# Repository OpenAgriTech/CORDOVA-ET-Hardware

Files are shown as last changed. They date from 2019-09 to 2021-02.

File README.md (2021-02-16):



# CORDOVA-ET-Hardware
Hardware parts for the CORDOVA-ET system.

## What is CORDOVA-ET?
The COnductance Recording Device for Observation and Validation of EvapoTranspiration (CORDOVA-ET) is a set of different components and instruments designed to record micrometeorological variables required for the calculation of evapotranspiration (ET) using the energy balance (EB) method. It has been developed by the University of Cordoba ([UCO](https://www.uco.es/)) and the [IAS-CSIC](https://www.ias.csic.es/) as part of the [SIDA-FAO project](http://www.fao.org/3/ca8794en/CA8794EN.pdf).

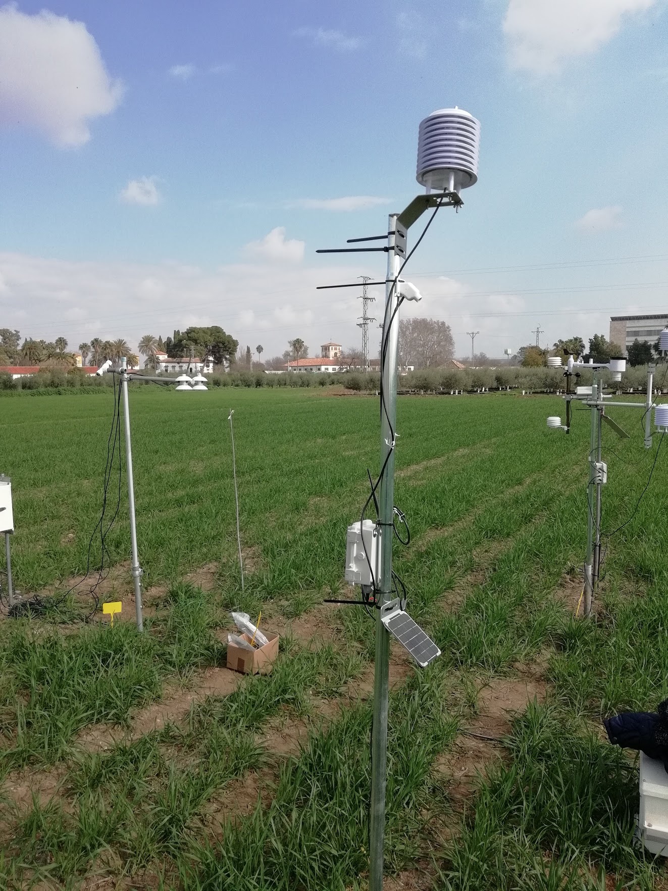
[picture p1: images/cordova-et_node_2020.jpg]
CORDOVA-ET Node during field validation in Cordoba 2020


For more information, you can join FAO's D-Groups on Water Productiviy and Agriculture, where you can view the webinars explaining the system and download manuals and troubleshooting guides. [D-groups access](https://dgroups.org/fao/waterproductivity/cordova_et)

## Hardware
The system consists on a group of LoRaWAN nodes that can measure simultaneously infrared temperature, air temperature and humidity as well as solar radiation.

This repository contains the design files to build a node yourself, including PCBs and 3D printed parts.

## Software
The code for the nodes can be found [here](https://github.com/OpenAgriTech/CORDOVA-ET-node)

## License
Licensed under Creative Commons Attribution-NonCommercial-ShareAlike 4.0 International (CC BY-NC-SA 4.0). See LICENSE.md for more info.

IAS-CSIC & University of Cordoba, 2021

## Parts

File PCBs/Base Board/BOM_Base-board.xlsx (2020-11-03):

Designator | Manufacturer Part Number or Seeed SKU | Qty | Link
J7 | 640453-6 | 1 | https://www.seeedstudio.io/opl.html
U5 | B2B-PH-K-S(LF)(SN) | 1 | https://www.seeedstudio.io/opl.html
J6 | 1751251 | 1 | https://www.seeedstudio.io/opl.html
R1,R4 | RC0603FR-074K7L | 2 | https://www.seeedstudio.io/opl.html
J8,J1 | 1125S-4P | 2 | https://www.seeedstudio.io/opl.html
J4 | 1125S-4P | 1 | https://www.seeedstudio.io/opl.html
J5 | 1125S-4P | 1 | https://www.seeedstudio.io/opl.html
J9 | 1125S-4P | 1 | https://www.seeedstudio.io/opl.html
R5 | RC0603FR-07115KL | 1 | https://www.seeedstudio.io/opl.html
R6 | RC0603FR-0756KL | 1 | https://www.seeedstudio.io/opl.html
SW1 | JS202011SCQN | 1 | https://www.seeedstudio.io/opl.html

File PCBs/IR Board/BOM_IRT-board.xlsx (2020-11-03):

Designator | MNP | Qty | Link
U1 | XC6206P302MR | 1 | https://statics3.seeedstudio.com/images/opl/datasheet/310030009.pdf
C3 | TAJA106K016RNJ | 1 | https://statics3.seeedstudio.com/images/opl/datasheet/0130050P1.pdf
C1,C2 | CC0402KRX7R8BB104 | 2 | https://statics3.seeedstudio.com/images/opl/datasheet/302010024.pdf
R1,R2 | RC0603FR-074K7L | 2 | https://statics3.seeedstudio.com/images/opl/datasheet/resistance-series.pdf
J2 | 1125S-4P | 1 | https://statics3.seeedstudio.com/images/opl/datasheet/3470130P1.pdf

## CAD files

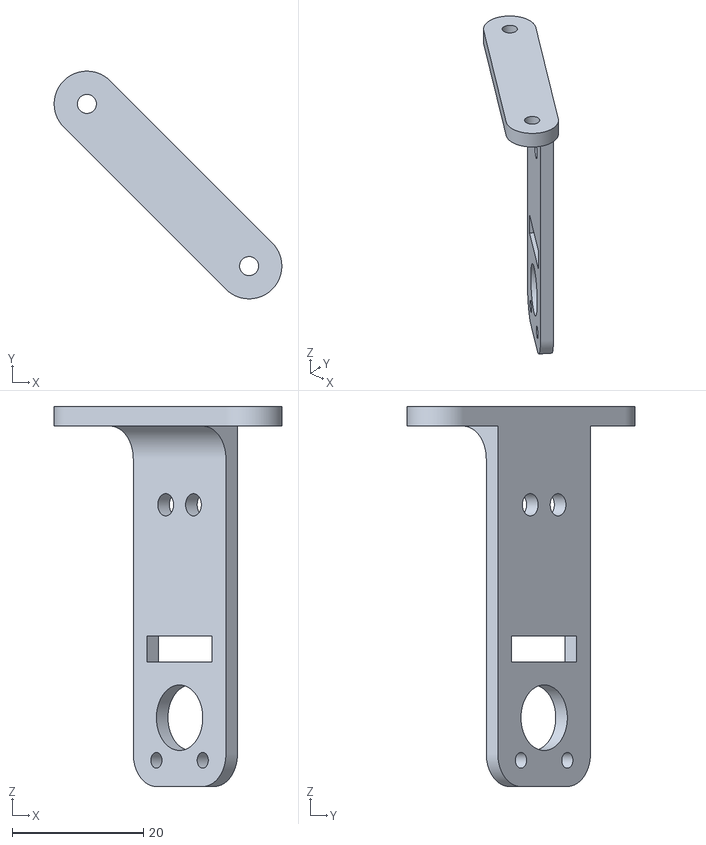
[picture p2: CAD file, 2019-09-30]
3D Printing/SHT3x support.stl
34.7 x 34.7 x 58.0

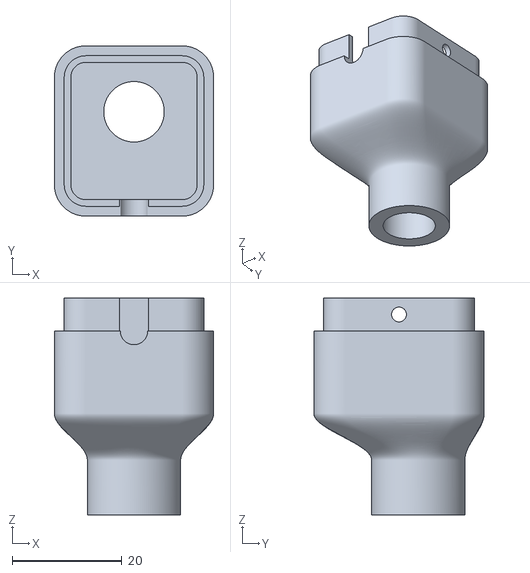
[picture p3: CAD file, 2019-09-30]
3D Printing/IRT_Case - Cover v3.stl
29.0 x 31.0 x 39.5

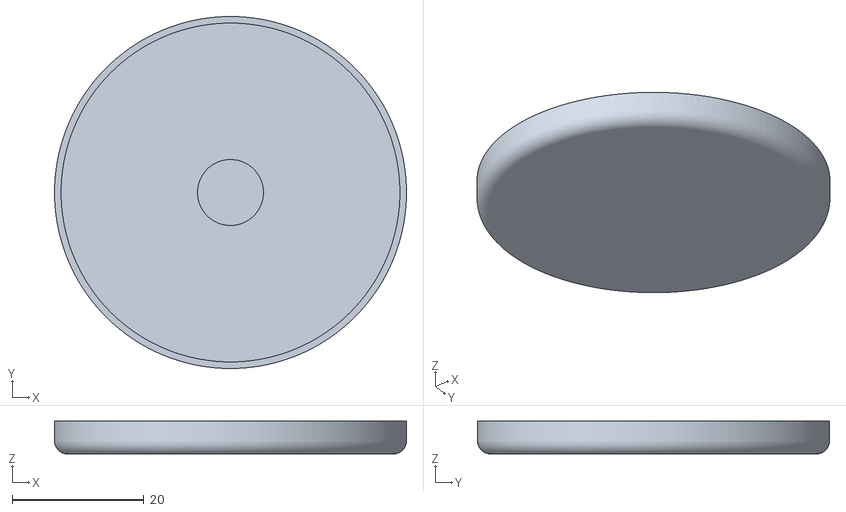
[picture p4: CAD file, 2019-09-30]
3D Printing/Pyranometer_cover_white.stl
53.4 x 53.4 x 5.00

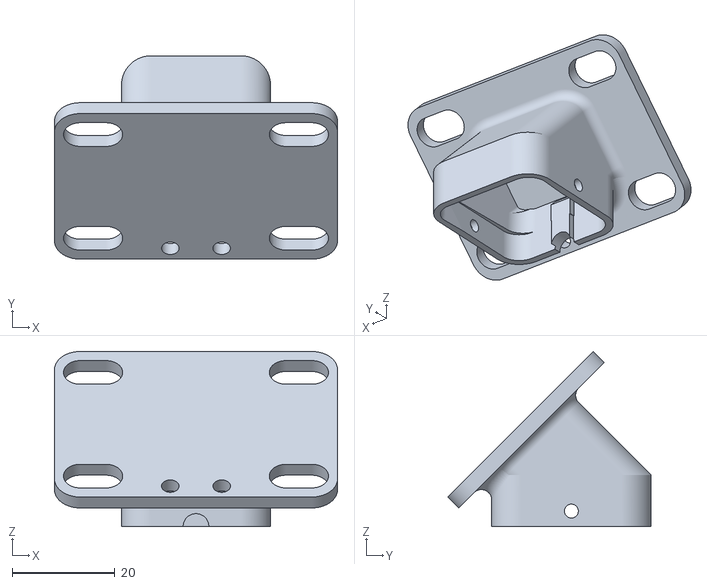
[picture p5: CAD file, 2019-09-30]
3D Printing/IRT_Case - Base v3.stl
55.0 x 39.5 x 34.0

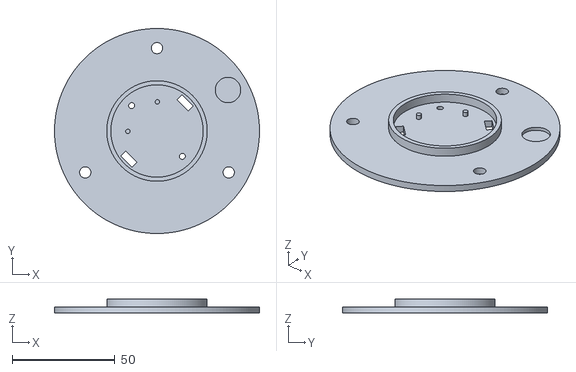
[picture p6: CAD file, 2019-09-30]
3D Printing/Pyranometer.stl
100.0 x 100.0 x 7.00

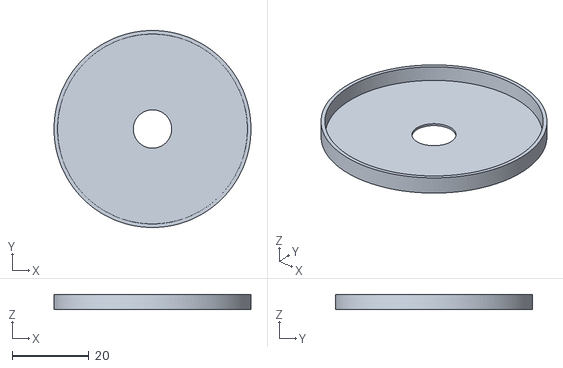
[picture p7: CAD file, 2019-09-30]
3D Printing/Pyranometer_cover_black.stl
51.4 x 51.4 x 4.00

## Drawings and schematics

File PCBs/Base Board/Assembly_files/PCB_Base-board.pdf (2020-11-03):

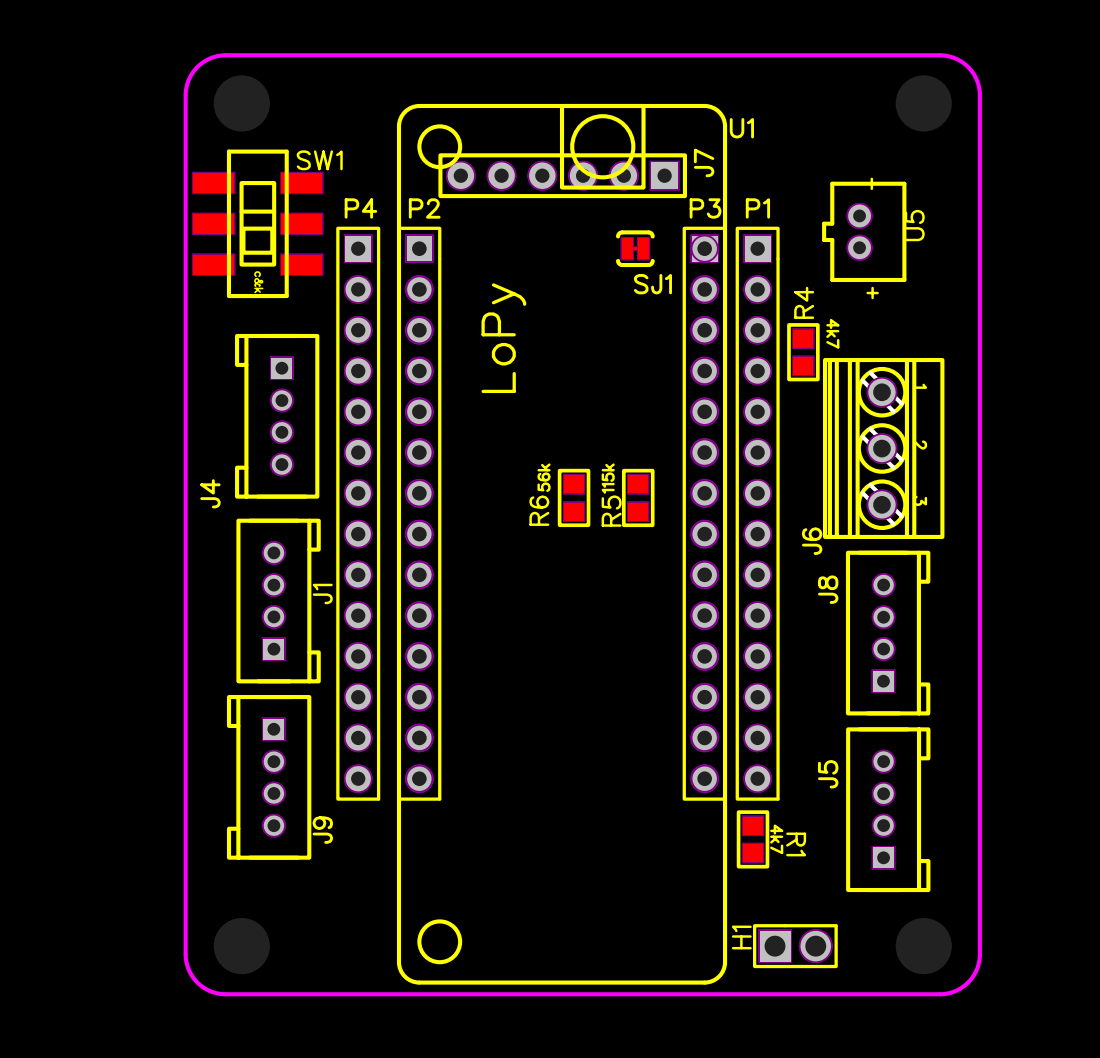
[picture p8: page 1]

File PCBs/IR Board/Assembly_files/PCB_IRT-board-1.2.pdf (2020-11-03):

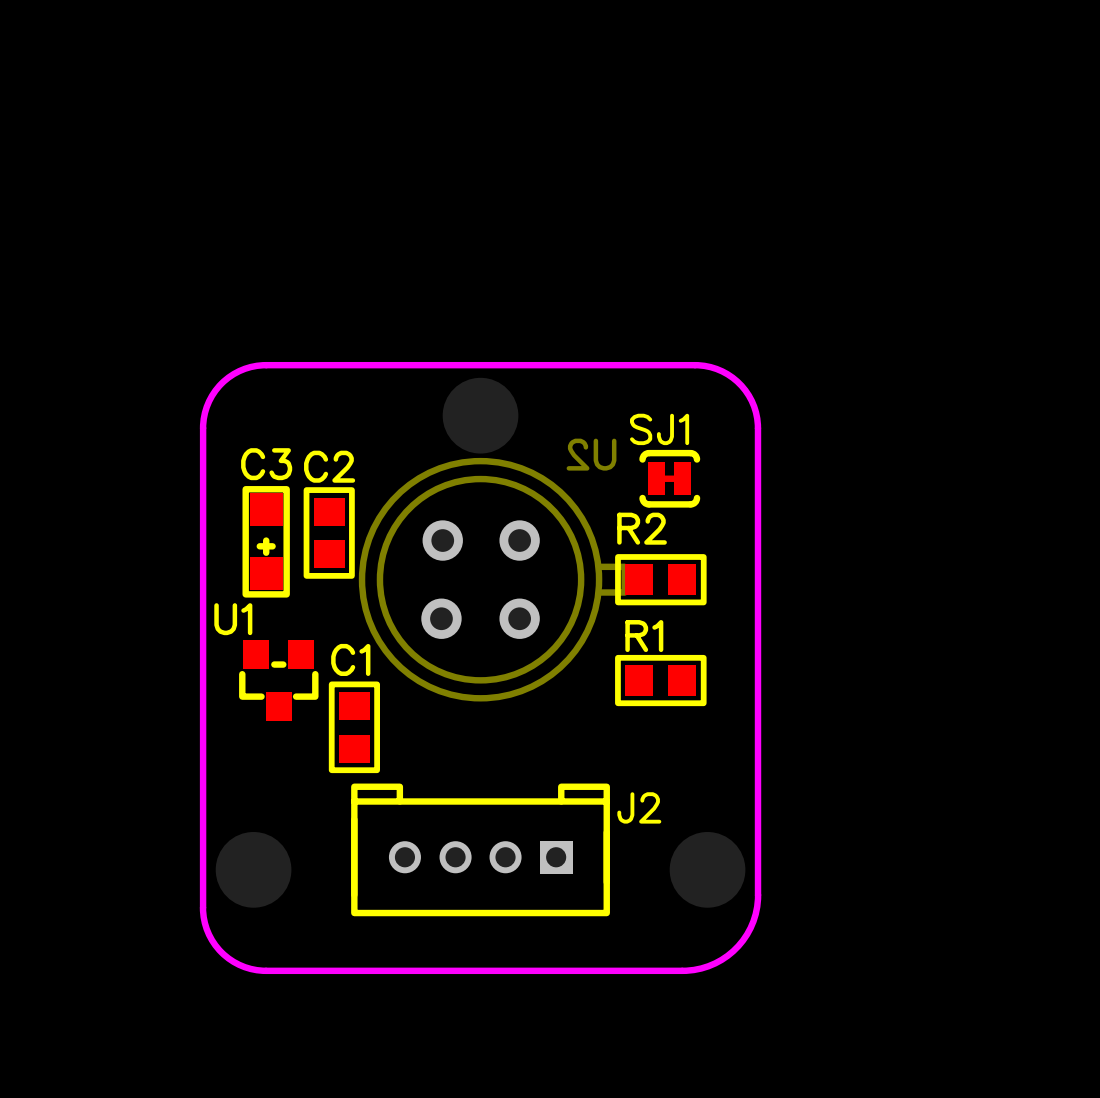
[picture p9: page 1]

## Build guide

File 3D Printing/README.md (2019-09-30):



# 3D printed parts

## 3D printer
We mainly use an [Ultimaker S5](https://ultimaker.com/3d-printers/ultimaker-s5) for production
3D printing.

## Materials
The material used for 3D printed parts of the CORDOVA-ET is white PETG from
[Smart Materials 3D](https://www.smartmaterials3d.com/en/home/24-petg.html#/size-750g/shoes_size-2_85_mm/colour-white).
After several tests, this is the material that showed the best resistance
to harsh outdoor conditions.

In the pyranometer, we have used [Black ASA](https://www.smartmaterials3d.com/en/home/196-asa.html#/size-750g/shoes_size-1_75mm/colour-black)
in the second extruder for providing mate black inline to avoid extra radiation
reaching the radiation sensor.

## Pyranometer
It is composed of the Pyranometer enclosure and the cover. For the cover
it needs to be printed with a dual extruder 3D printed using white PETG and black ASA

## Air temperature and humidity sensor support
The SHT3x is attached to a vertical mount attached to the pyranometer using two
screws. The sensor can be mounted using tiny screws or a small pice of wire.

## Infrared Thermometer Case
The Melexis sensor is housed in a case that allows to mount the sensor on a vertical
bar. The two parts are assembled together using two small screws.

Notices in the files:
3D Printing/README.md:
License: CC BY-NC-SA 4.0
